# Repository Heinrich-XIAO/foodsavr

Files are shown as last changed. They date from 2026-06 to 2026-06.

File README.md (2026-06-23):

# foodsavr
~30% of food in the world is wasted and sent to landfills. foodsavr is a gadget that magnetically attaches to your fridge to remind you what food is close to expiring.

## Usage
To add a food item:
Show your food item to the camera and press the A button. Then, enter the expiry date of the item with the number pad. Finally, confirm by pressing the A button again. Press D to cancel.

Press B and C to cycle up and down through the list of food items.

## Technical Details
foodsavr uses two microcontrollers. The ESP-32 CAM is used for the camera, but since it doesn't have enough pins, another board is necessary. The other dev board is an off-brand pico-like RP2040 board. For the display, it uses an E-Ink display from WeAct Studio. The matrix keypad is your standard membrane keypad that is in every single electronics kit. It uses a set of lipos for power with USB-C charging. The charger board is TP4056-based.

## Build Guide
1. Insert the battery's JST connector into the charging board.
2. Insert the keypad's cable into its 1x8 header, with the keypad being in the slot on the top case.
3. Put the E-Ink display on the 2x4 header on the PCB.
4. Plop the top case on the display so that the screw holes of the display line up.
5. Use the M3 nuts and bolts to secure the display.
6. For the two corners on the right, insert the M3 heatset inserts into the holes.
7. Add a thin layer of cyanoacryalte glue around the bottom of the magnet holes. Then, insert the magnets.
8. Send a right angled USB-C cable through the hole in the bottom case and plug it into the off brand USB-C Pico. Send a normal USB-C cable through the same hole and plug it into the battery charging board (The hole is large enough to accommodate two cables.)
9. Finally, fasten the bottom case so that the PCB rests in the tray with the M3.

## Motivation
I designed this because I got tired of leaving food at the back of my fridge to rot. Especially, since I'd save my favourite foods for later, and yet forget about them until expiry. This project reminds you before they expire so that you never leave food in the back of your fridge for too long.

## BOM
|Name |Links |Price (CAD)|
|---|---|---|
|PCB |https://jlcpcb.com/ |$6.66 |
|E-Paper Screen |https://www.aliexpress.com/item/1005007133350270.html|$30.45 |
|Ferrite Magnets (10x3mm) |https://www.aliexpress.com/item/1005008858265927.html|$11.24 |
|Fake Pico |https://www.aliexpress.com/item/1005005617180169.html|$3.07 |
|Number Pad |https://www.aliexpress.com/item/1005009455766218.html|$2.14 |
|4x 18650 12000mAh |https://www.aliexpress.com/item/1005009903616172.html|$39.40 |
|TP4056 JST USB-C Module |https://www.aliexpress.com/item/1005006943878636.html|$2.62 |
|Voltage Booster |https://www.aliexpress.com/item/1005007385896399.html|$3.48 |
|Right-Angle Headers |https://www.aliexpress.com/item/1005006795400618.html|$4.07 |
|ESP32 CAM w/ Flasher |https://www.aliexpress.com/item/1005006137530316.html|$13.52 |
|M3x10mm with nut |https://www.aliexpress.com/item/32799844538.html |$3.31 |
|Heatset Inserts (M3 5mm OD w/ 10mm length) |https://www.aliexpress.com/item/1005003582355741.html|$3.93 |
|Right angled USBC cable|https://ja.aliexpress.com/item/1005009168667192.html|$6.48|
|Subtotal |N/A |$130.37 |
|Total (After Aliexpress Discounts subject to change)|N/A |CAD$97.06  |
|USD Total |N/A |USD$68.54  |

## Assembled 3D Model


https://cad.onshape.com/documents/8ee8f266d123a24e5a0ce496/w/151140d60200875ea61c9eed/e/18a74606bdcc9369348646ee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

## PCB
3D_PCB1_2026-06-06

## Schematic


## Zine Page
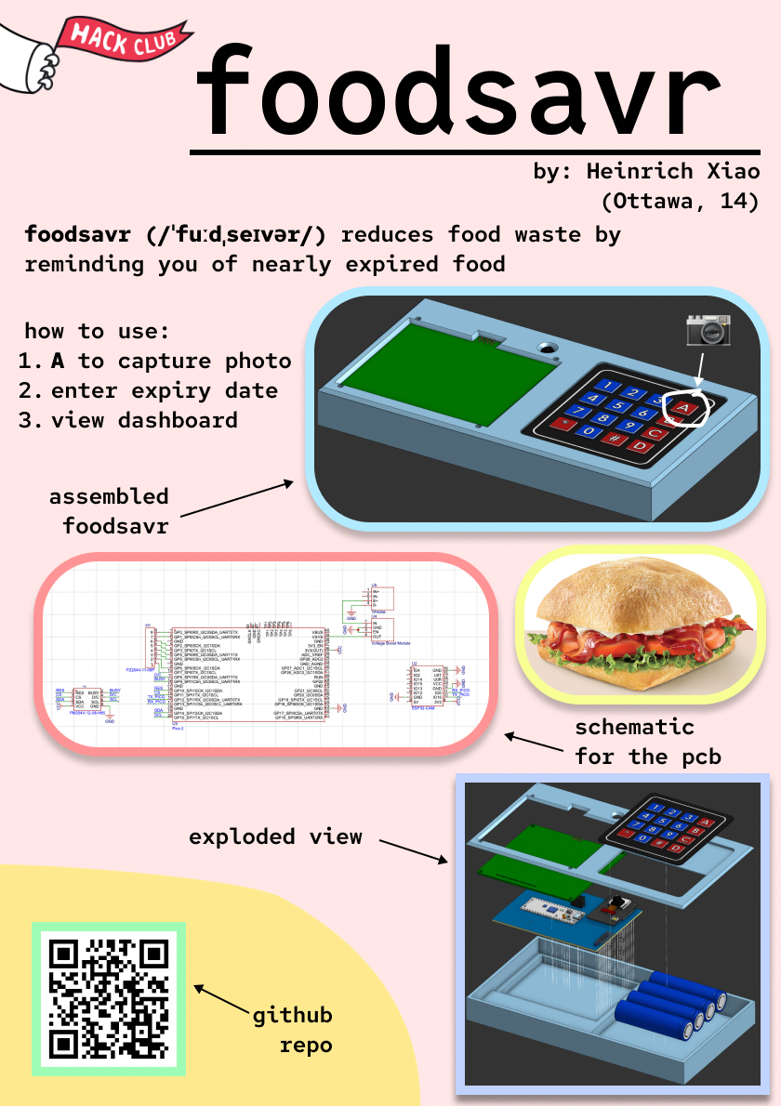
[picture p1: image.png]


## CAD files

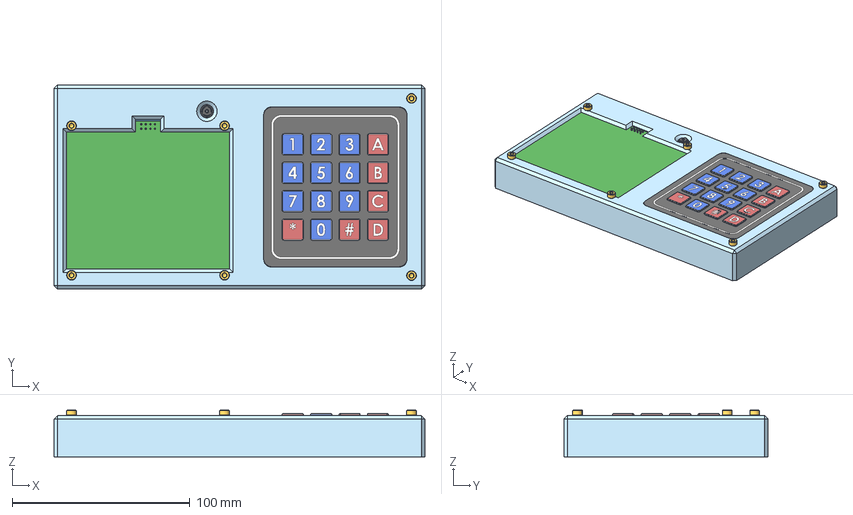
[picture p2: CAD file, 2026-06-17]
3d/assembly.step
209.0 x 115.0 x 26.3 mm
pin_header_awl254-dg-g08d
95263A134_NO THREADS_Alloy Steel Socket Head Screw x 6
id44
RASPBERRY PI PICO FOOTPRINT~Pico-R3~6giG x 16
COMM-TH_16P-L40.0-W27.0-P2.54_ESP32-CAM~ESP3-CAM~MHXI x 45
id120 x 8
id145 x 8
Board~UleJ
HDR-TH_8P-P2.54-V-F-R2-C4-S2.54~HDR-TH_8P-P2.54-F-LI-2X4P~TKbx
RASPBERRY PI PICO FOOTPRINT~Pico-R3~6giG_1

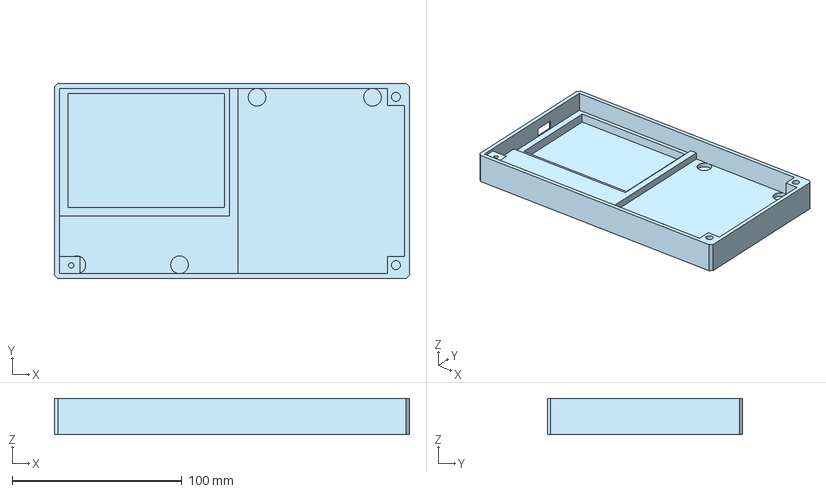
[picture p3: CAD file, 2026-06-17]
3d/bottom_case.step
209.0 x 115.0 x 21.3 mm

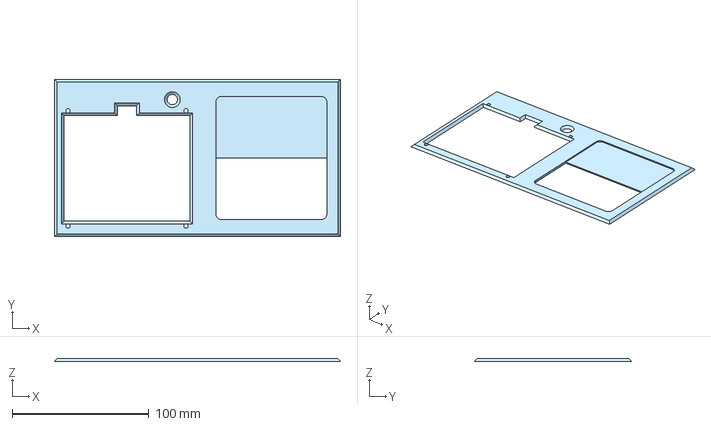
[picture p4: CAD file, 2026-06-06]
3d/top_case.step
209.0 x 115.0 x 2.00 mm

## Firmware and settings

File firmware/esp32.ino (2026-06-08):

#include "esp_camera.h"
#include "Arduino.h"
#include "FS.h"                // SD Card ESP32
#include "SD_MMC.h"            // SD Card ESP32
#include "soc/soc.h"           // Disable brownout problems
#include "soc/rtc_cntl_reg.h"  // Disable brownout problems
#include "driver/rtc_io.h"
#include <EEPROM.h>            // read and write from flash memory

// Define the number of bytes you want to access
#define EEPROM_SIZE 1

// Pin definition for CAMERA_MODEL_AI_THINKER
#define PWDN_GPIO_NUM     32
#define RESET_GPIO_NUM    -1
#define XCLK_GPIO_NUM      0
#define SIOD_GPIO_NUM     26
#define SIOC_GPIO_NUM     27

#define Y9_GPIO_NUM       35
#define Y8_GPIO_NUM       34
#define Y7_GPIO_NUM       39
#define Y6_GPIO_NUM       36
#define Y5_GPIO_NUM       21
#define Y4_GPIO_NUM       19
#define Y3_GPIO_NUM       18
#define Y2_GPIO_NUM        5
#define VSYNC_GPIO_NUM    25
#define HREF_GPIO_NUM     23
#define PCLK_GPIO_NUM     22

// Flash LED pin
#define FLASH_LED_PIN      4

int pictureNumber = 0;

void eeprom_init() {
  // Initialize EEPROM first to get picture number
  EEPROM.begin(EEPROM_SIZE);
  pictureNumber = EEPROM.read(0) + 1;
  
  // Handle overflow (reset to 1 if it exceeds 255)
  if (pictureNumber > 255) {
    pictureNumber = 1;
  }

  Serial.printf("Taking picture number: %d\n", pictureNumber);
}

void sd_card_init() {
  // Initialize SD Card BEFORE camera to reduce memory pressure
  Serial.println("Starting SD Card");
  if (!SD_MMC.begin()) {
    Serial.println("SD Card Mount Failed");
    goToSleep(); 
    return;
  }

  uint8_t cardType = SD_MMC.cardType();
  if (cardType == CARD_NONE) {
    Serial.println("No SD Card attached");
    goToSleep(); 
    return;
  }

  Serial.printf("SD Card Type: ");
  if (cardType == CARD_MMC) {
    Serial.println("MMC");
  } else if (cardType == CARD_SD) {
    Serial.println("SDSC");
  } else if (cardType == CARD_SDHC) {
    Serial.println("SDHC");
  } else {
    Serial.println("UNKNOWN");
  }
}

void camera_config() {
  // Camera configuration - REDUCED settings to prevent stack overflow
  camera_config_t config;
  config.ledc_channel = LEDC_CHANNEL_0;
  config.ledc_timer = LEDC_TIMER_0;
  config.pin_d0 = Y2_GPIO_NUM;
  config.pin_d1 = Y3_GPIO_NUM;
  config.pin_d2 = Y4_GPIO_NUM;
  config.pin_d3 = Y5_GPIO_NUM;
  config.pin_d4 = Y6_GPIO_NUM;
  config.pin_d5 = Y7_GPIO_NUM;
  config.pin_d6 = Y8_GPIO_NUM;
  config.pin_d7 = Y9_GPIO_NUM;
  config.pin_xclk = XCLK_GPIO_NUM;
  config.pin_pclk = PCLK_GPIO_NUM;
  config.pin_vsync = VSYNC_GPIO_NUM;
  config.pin_href = HREF_GPIO_NUM;
  config.pin_sccb_sda = SIOD_GPIO_NUM;
  config.pin_sccb_scl = SIOC_GPIO_NUM;
  config.pin_pwdn = PWDN_GPIO_NUM;
  config.pin_reset = RESET_GPIO_NUM;
  config.xclk_freq_hz = 20000000;
  config.pixel_format = PIXFORMAT_JPEG;

  // CRITICAL: Reduced frame size and quality to prevent stack overflow
  if (psramFound()) {
    Serial.println("PSRAM found");
    config.frame_size = FRAMESIZE_XGA;  // Reduced from UXGA to XGA
    config.jpeg_quality = 12;           // Increased from 10 to 12 (lower quality, smaller file)
    config.fb_count = 1;                // Reduced from 2 to 1 to save memory
  } else {
    Serial.println("PSRAM not found");
    config.frame_size = FRAMESIZE_VGA;  // Reduced from SVGA to VGA
    config.jpeg_quality = 15;           // Lower quality for boards without PSRAM
    config.fb_count = 1;
  }
  
  // Additional memory-saving configurations
  config.grab_mode = CAMERA_GRAB_LATEST; // Changed from WHEN_EMPTY to LATEST
}

void camera_init() {
  // Initialize Camera
  esp_err_t err = esp_camera_init(&config);
  if (err != ESP_OK) {
    Serial.printf("Camera init failed with error 0x%x\n", err);
    goToSleep();
    return;
  }
  Serial.println("Camera initialized successfully");

  // Additional sensor settings to optimize for memory usage
  sensor_t * s = esp_camera_sensor_get();
  if (s != NULL) {
    // Lower the resolution if needed
    // s->set_framesize(s, FRAMESIZE_VGA);
    
    // Optimize other settings
    s->set_brightness(s, 0);     // -2 to 2
    s->set_contrast(s, 0);       // -2 to 2
    s->set_saturation(s, 0);     // -2 to 2
    s->set_special_effect(s, 0); // 0 to 6 (0 - No Effect)
    s->set_whitebal(s, 1);       // 0 = disable , 1 = enable
    s->set_awb_gain(s, 1);       // 0 = disable , 1 = enable
    s->set_wb_mode(s, 0);        // 0 to 4 - if awb_gain enabled
    s->set_exposure_ctrl(s, 1);  // 0 = disable , 1 = enable
    s->set_aec2(s, 0);           // 0 = disable , 1 = enable
    s->set_ae_level(s, 0);       // -2 to 2
    s->set_aec_value(s, 300);    // 0 to 1200
    s->set_gain_ctrl(s, 1);      // 0 = disable , 1 = enable
    s->set_agc_gain(s, 0);       // 0 to 30
    s->set_gainceiling(s, (gainceiling_t)0);  // 0 to 6
    s->set_bpc(s, 0);            // 0 = disable , 1 = enable
    s->set_wpc(s, 1);            // 0 = disable , 1 = enable
    s->set_raw_gma(s, 1);        // 0 = disable , 1 = enable
    s->set_lenc(s, 1);           // 0 = disable , 1 = enable
    s->set_hmirror(s, 0);        // 0 = disable , 1 = enable
    s->set_vflip(s, 0);          // 0 = disable , 1 = enable
    s->set_dcw(s, 1);            // 0 = disable , 1 = enable
    s->set_colorbar(s, 0);       // 0 = disable , 1 = enable
  }
}

void shoot_and_save() {
  // Take Picture with Camera
  Serial.println("Taking picture...");
  camera_fb_t *fb = NULL;
  
  // Try to take picture with retries
  for (int retry = 0; retry < 3; retry++) {
    fb = esp_camera_fb_get();
    if (fb) break;
    Serial.printf("Camera capture failed, retry %d\n", retry + 1);
    delay(500);
  }
  
  if (!fb) {
    Serial.println("Camera capture failed after retries");
    goToSleep();
    return;
  }
  Serial.printf("Picture taken! Size: %zu bytes\n", fb->len);

  // Create file path
  String path = "/picture" + String(pictureNumber) + ".jpg";
  
  // Save picture to SD card
  fs::FS &fs = SD_MMC;
  Serial.printf("Picture file name: %s\n", path.c_str());

  File file = fs.open(path.c_str(), FILE_WRITE);
  if (!file) {
    Serial.println("Failed to open file in writing mode");
    esp_camera_fb_return(fb);
    goToSleep();
    return;
  }

  // Write file in chunks to prevent memory issues
  size_t totalBytes = fb->len;
  size_t bytesWritten = 0;
  const size_t chunkSize = 1024; // Write in 1KB chunks
  
  while (bytesWritten < totalBytes) {
    size_t toWrite = min(chunkSize, totalBytes - bytesWritten);
    size_t written = file.write(fb->buf + bytesWritten, toWrite);
    if (written != toWrite) {
      Serial.println("Write error occurred");
      break;
    }
    bytesWritten += written;
  }
  
  file.close();
  
  if (bytesWritten == totalBytes) {
    Serial.printf("Saved file to path: %s (%zu bytes)\n", path.c_str(), bytesWritten);
    
    // Update picture number in EEPROM only after successful save
    EEPROM.write(0, pictureNumber);
    EEPROM.commit();
    Serial.println("Picture saved successfully!");
  } else {
    Serial.printf("File write incomplete: %zu/%zu bytes\n", bytesWritten, totalBytes);
  }
  
  // Return the frame buffer immediately after use
  esp_camera_fb_return(fb);
}

void setup() {
  WRITE_PERI_REG(RTC_CNTL_BROWN_OUT_REG, 0);  // Disable brownout detector

  Serial.begin(115200);
  Serial.println("ESP32-CAM Photo Capture Starting...");

  Serial1.begin(115200);
  Serial1.setTX(0);
  Serial1.setRX(16);

  eeprom_init();
  sd_card_init();

  camera_config();
  camera_init();

  // Wait a moment for camera to stabilize
  delay(1000);

  shoot_and_save();
  
  // Brief delay before sleep
  delay(500);
  
  goToSleep();
}

void goToSleep() {
  // Deinitialize camera to free memory before sleep
  esp_camera_deinit();
  
  // Turn off the ESP32-CAM white on-board LED (flash) connected to GPIO 4
  pinMode(FLASH_LED_PIN, OUTPUT);
  digitalWrite(FLASH_LED_PIN, LOW);
  rtc_gpio_hold_en(GPIO_NUM_4);

  Serial.println("Going to sleep now");
  Serial.flush();
  
  delay(100);
  
  esp_deep_sleep_start();
}

void loop() {
    if (Serial1.available()) {
        String cmd = Serial1.readStringUntil('\n');
        cmd.trim();

        if (cmd == "SHOOT") {
            sendImage();
        }
    } else {
        Serial.println("Serial1 not available.")
    }
}

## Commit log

2026-06-02 Add new item for 4-battery 12000mAh in README
2026-06-03 Add TP4056 JST Connector Module to README
2026-06-03 Revise BOM prices in README.md
    Updated prices for components in the BOM section.
2026-06-05 Fix price of 4.2" E-Ink Screen in README
    Updated the price of the 4.2" E-Ink Screen in the BOM.
2026-06-05 Fix RP2040 Pico description in BOM
2026-06-06 Update README with 3D model images
    Added sections for exploded and assembled 3D models with images.
2026-06-06 Add PCB section with image to README
    Added PCB section with image to README.
2026-06-06 Add bill of materials (bom.csv) with components list
    [bom.csv]
2026-06-06 Update BOM section to reference BOM.csv
    Removed individual BOM item links and referenced BOM.csv instead.
2026-06-06 purchase links
    [BOM.csv]
2026-06-06 add 3d files and link to onshape
    [bottom_case.step, top_case.step]
2026-06-07 update bom.csv to try to fix fallout thing
    [BOM.csv]
2026-06-11 Add build guide to README
    Added a build guide section with step-by-step instructions for assembling the device.
2026-06-12 Revise display installation steps in README
    Updated instructions for securing the display and added a step for inserting heatset inserts.
2026-06-12 Update BOM with new items and revised totals
    [BOM.csv]
2026-06-12 Update description of Heatset Inserts in BOM.csv
    [BOM.csv]
2026-06-12 Replace Assembled 3D Model image
    Updated the Assembled 3D Model section with a new image.
2026-06-20 add bom table to readme
